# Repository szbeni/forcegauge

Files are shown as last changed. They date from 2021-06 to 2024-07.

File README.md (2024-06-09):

# Force Gauge

- ESP32 based Force Gauge - Aiming to help rock climbing specific training (finger excercises)
- Real time plotting via wifi Webapp/Android app

# Pictures
## Forcegauge with fingerboard
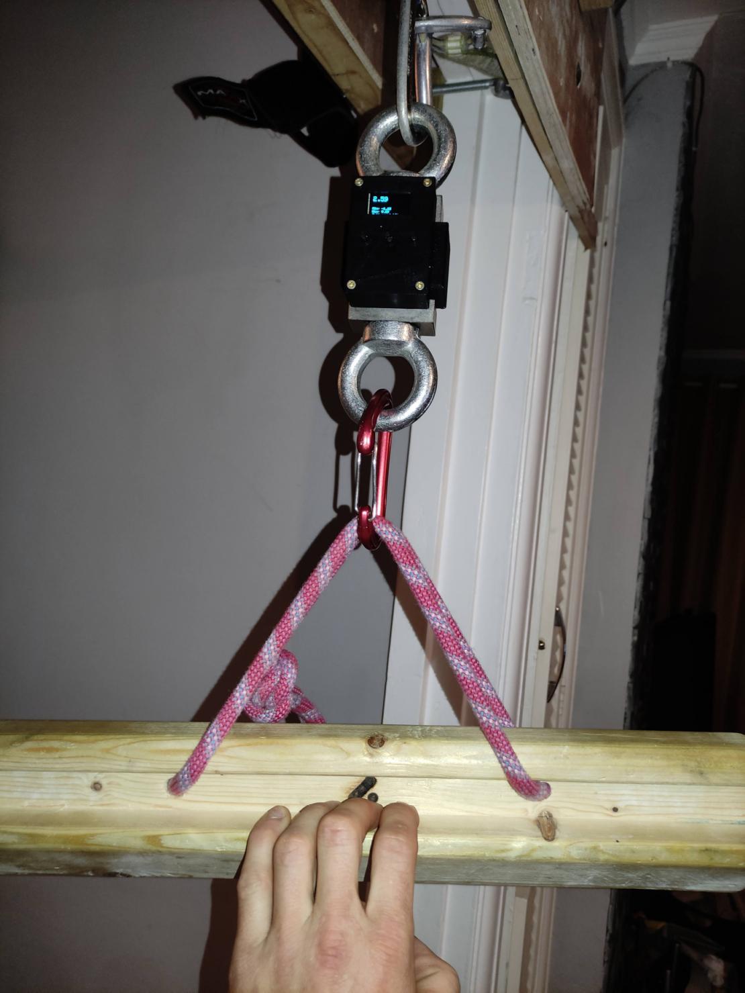
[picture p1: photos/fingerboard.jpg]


## First prototypes
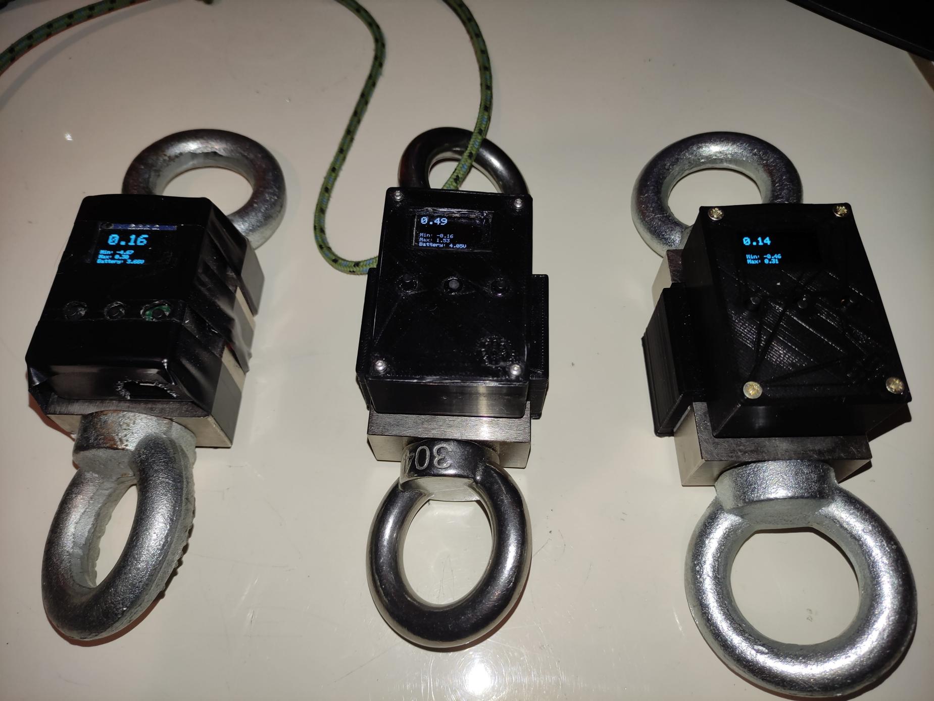
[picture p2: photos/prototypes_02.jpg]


# Hardware
## Main parts
 - ESP32-C3 MCU
 - 3 buttons
 - OLED screen 0.96" SSD1306
 - Battery with charger
 - USB UART connection
 - HX711 ADC - Load cell
## Schematic ##

- [Schematic](https://github.com/szbeni/forcegauge/blob/main/hw/forcegauge/forcegauge.pdf)
## PCB 

Pictures of the PCB:

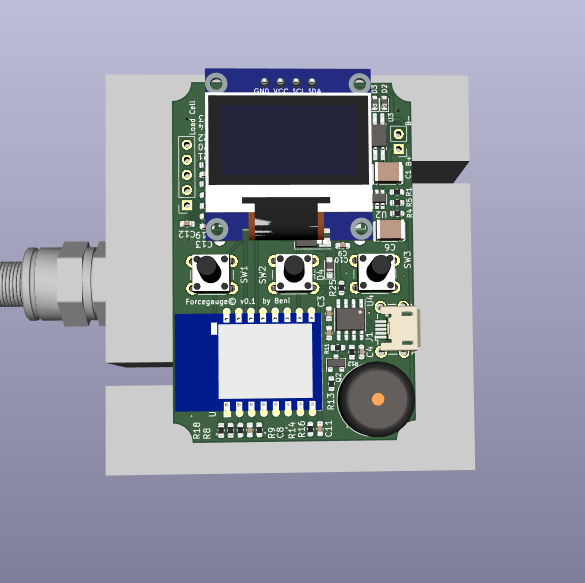
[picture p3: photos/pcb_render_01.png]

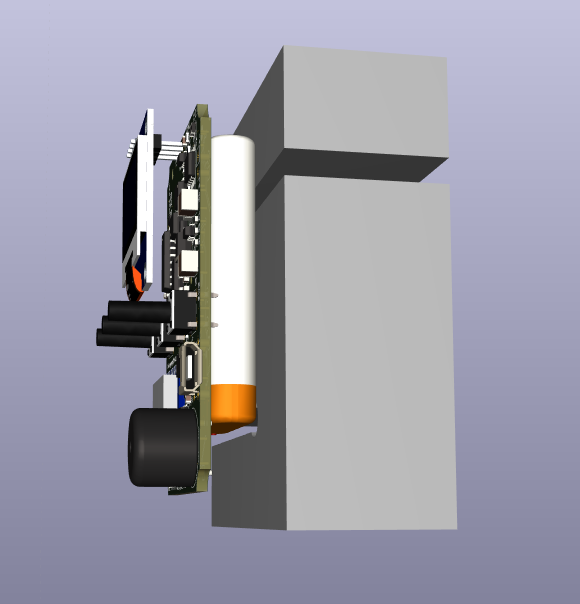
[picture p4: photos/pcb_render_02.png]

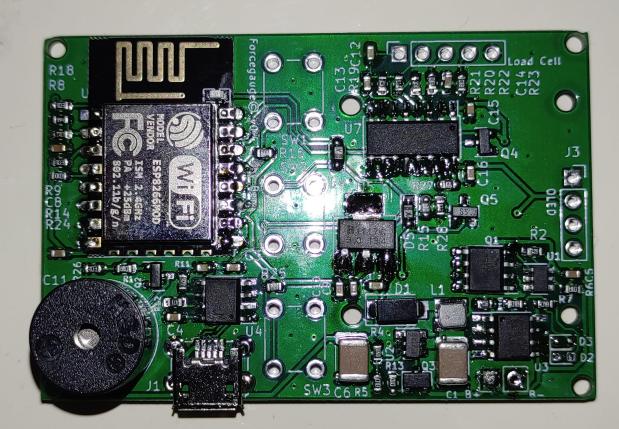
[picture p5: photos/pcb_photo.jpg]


## Interactive BOM

- [Interactive BOM](https://htmlpreview.github.io/?https://github.com/szbeni/forcegauge/blob/main/hw/forcegauge/bom/ibom.html)

# Software

## Firmware
- Arudino IDE - Some lagging issues due to limitations of arduino environment
- Started wokring on firmware with ESP-IDF which supports multitasking
- Added Bluetooth support to come up as a Tindeq Progressor bluetooth device (https://tindeq.com/product/progressor) (CChange Bluetooth and restart device, WIFI wont work when BT is on)
- Added Bluetooth support to come up as a Climbro bluetooth device (https://climbro.com/) (Change Bluetooth settings and restart device, WIFI wont work when BT is on)

## Flutter based app (Tested on Android)
- Available on Google play: https://play.google.com/store/apps/details?id=com.github.szbeni.forcegauge
- Real time plotting
- Built in tabata timer (Based on https://github.com/insin/tabata_timer)
- Record history of traning 

<p float="left">
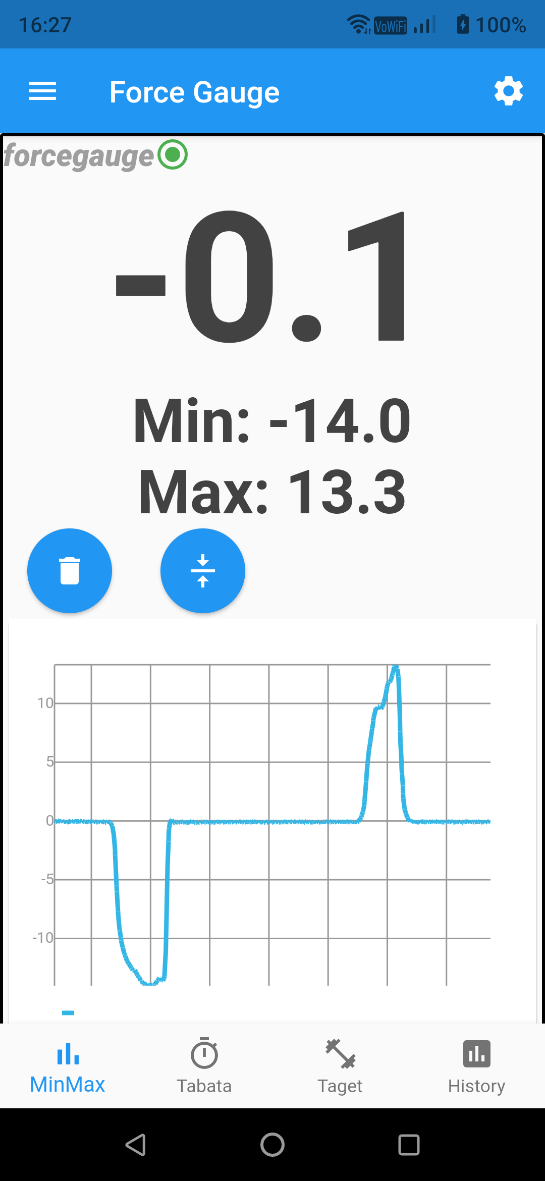
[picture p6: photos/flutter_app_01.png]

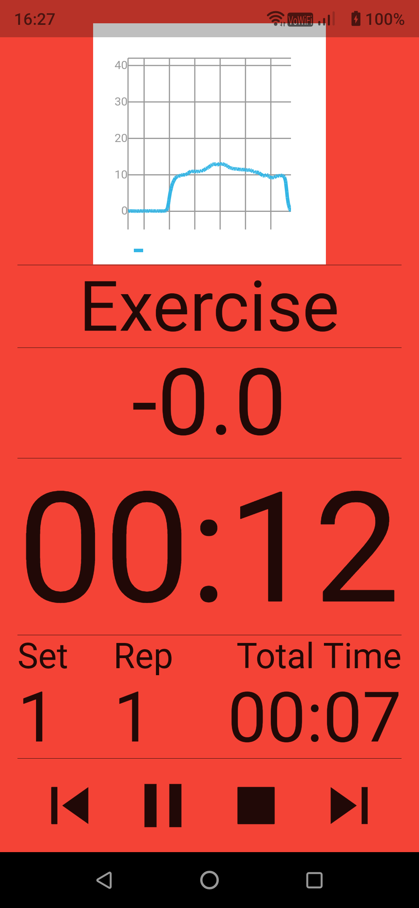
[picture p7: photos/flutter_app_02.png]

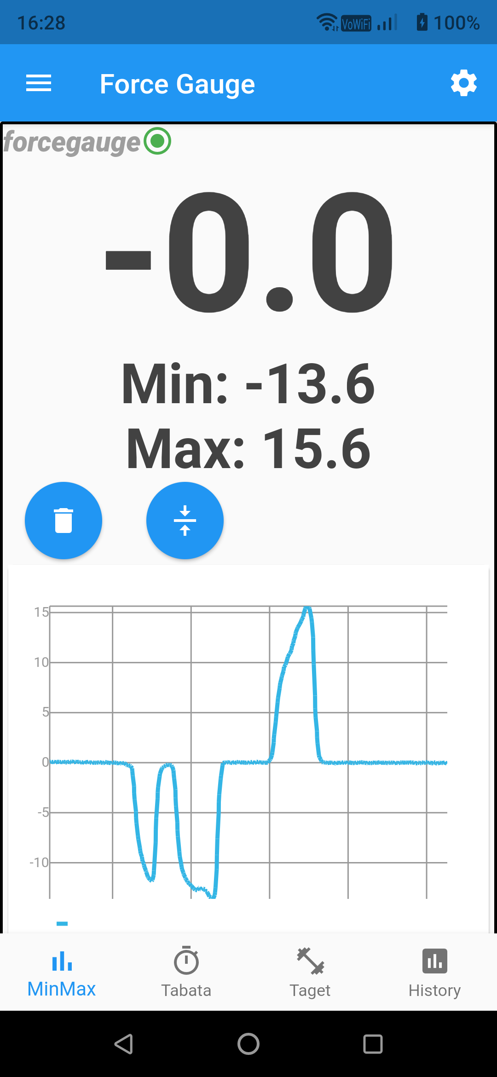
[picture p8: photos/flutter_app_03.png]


</p>

## Webapp
- Simple webapp served from a HTTP server

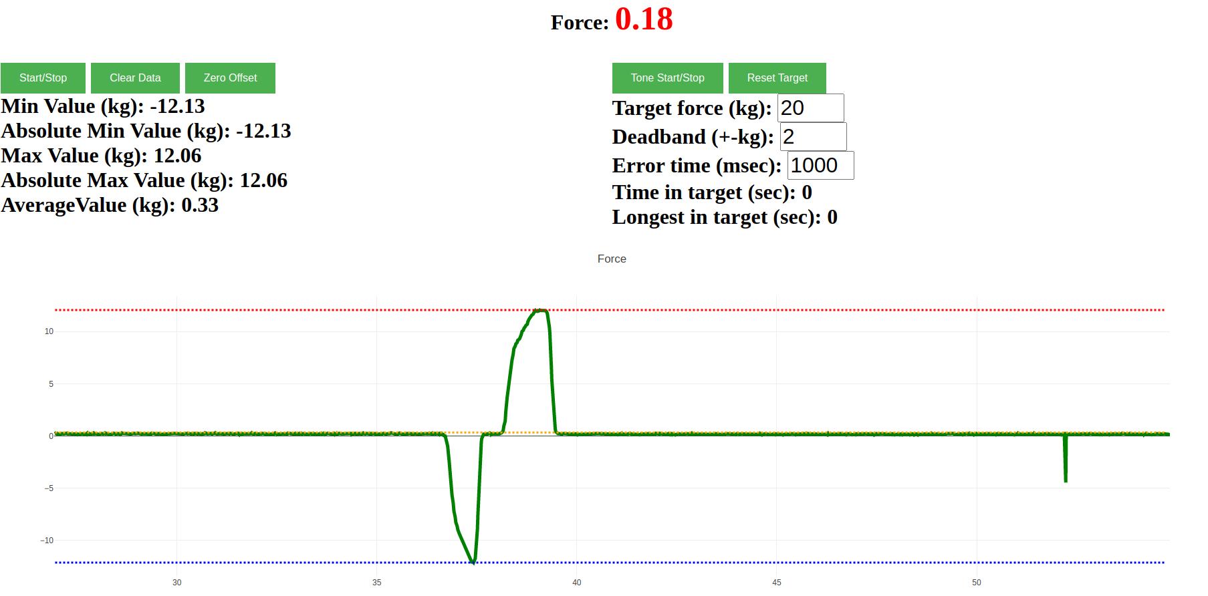
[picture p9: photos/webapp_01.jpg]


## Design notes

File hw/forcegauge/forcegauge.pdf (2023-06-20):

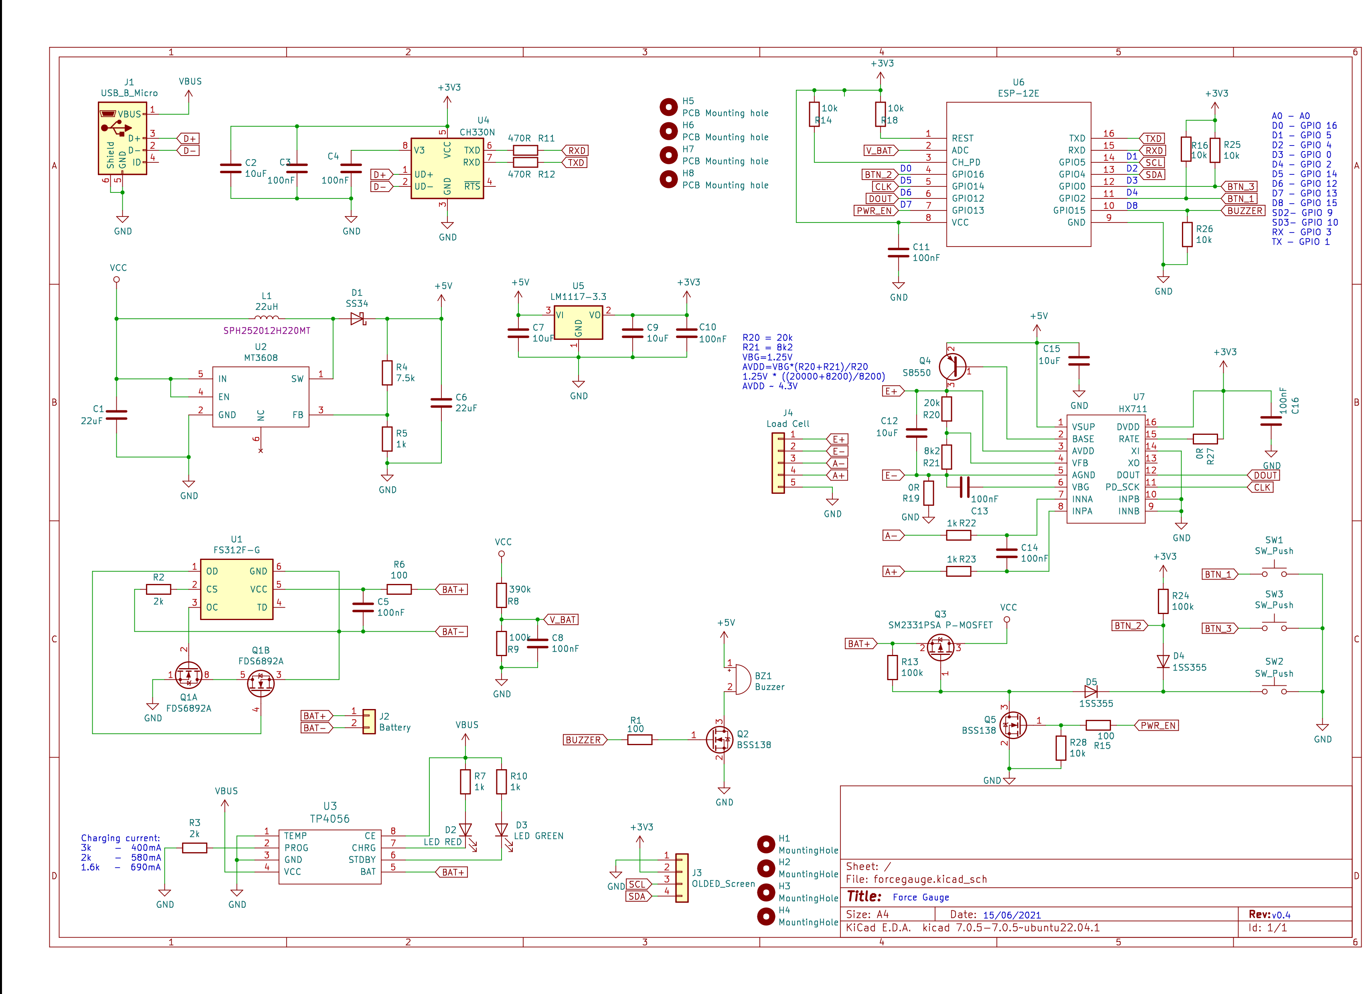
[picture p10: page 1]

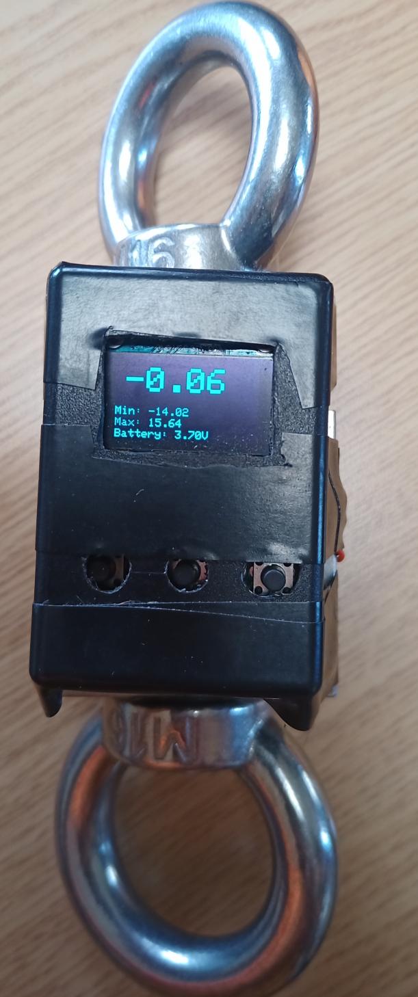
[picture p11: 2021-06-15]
photos/prototype_01.jpg

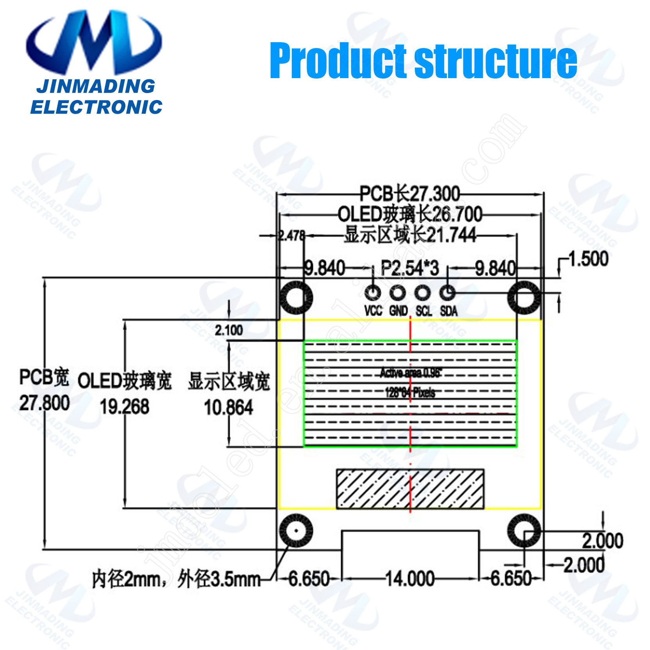
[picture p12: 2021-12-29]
hw/forcegauge/resources/oled_screen_dimensions.jpg

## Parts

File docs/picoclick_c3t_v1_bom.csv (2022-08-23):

Part | Value | Device | Package | Description
BAT+ | TP/SP-1.5X1.0 | TP/SP-1.5X1.0 | SOLDERPAD_1.5X1.0 | Solderpads/Testpads
BAT- | TP/SP-1.5X1.0 | TP/SP-1.5X1.0 | SOLDERPAD_1.5X1.0 | Solderpads/Testpads
C1 | 1µ | C-EU-0402-WOKEEPOUT_S | C0402_S
C2 | 1µ | C-EU-0402-WOKEEPOUT_S | C0402_S
C3 | 1µ | C-EU-0402-WOKEEPOUT_S | C0402_S
C4 | 1µ | C-EU-0402-WOKEEPOUT_S | C0402_S
C7 | 10µ | C-EU-0402-WOKEEPOUT_S | C0402_S
C8 | 0,1µ | C-EU-0402-WOKEEPOUT_S | C0402_S
C9 | 0,1µ | C-EU-0402-WOKEEPOUT_S | C0402_S
C13 | 1µ | C-EU-0402-WOKEEPOUT_S | C0402_S
C20 | 10p | C-EU-0402-WOKEEPOUT_S | C0402_S
C21 | 10p | C-EU-0402-WOKEEPOUT_S | C0402_S
D1 | 4148 | DIODE-SOD523 | SOD523 | DIODE
D2 | 4148 | DIODE-SOD523 | SOD523 | DIODE
ESP1 | ESP32_C3_QFN32 | ESP32_C3_QFN32 | QFN32
F2 | 0 | R-EU-0402-WOKEEPOUT | R0402
L1 | WS2812_2020 | WS2812_2020 | WS2812_2020
R/1 | 1M | R-EU-0402-WOKEEPOUT | R0402
R/2 | 250k | R-EU-0402-WOKEEPOUT | R0402
R1 | 1k | R-EU-0402-WOKEEPOUT | R0402
R2 | 1k | R-EU-0402-WOKEEPOUT | R0402
R3 | 1M | R-EU-0402-WOKEEPOUT | R0402
R4 | 10k | R-EU-0402-WOKEEPOUT | R0402
R5 | 47.5k | R-EU-0402-WOKEEPOUT | R0402
R7 | 10k | R-EU-0402-WOKEEPOUT | R0402
R10 | 10k | R-EU-0402-WOKEEPOUT | R0402
R11 | 10k | R-EU-0402-WOKEEPOUT | R0402
R12 | 5.1k | R-EU-0402-WOKEEPOUT | R0402
R13 | 5.1k | R-EU-0402-WOKEEPOUT | R0402
RF | ANT3216LL00R2400A | ANT3216LL00R2400A | ANT3216LL00R2400A
U$1 | BUTTON_ST-1187-3 | BUTTON_ST-1187-3 | BUTTON_ST-1187-3
U1 | BRCL4054BME | MCP73831_SOT23_5 | SOT23-5
U2 | MIC5504 | MIC5504 | TDFN4
USB-C | USB_C_C393939 | USB_C_C393939 | USBC_C393939
X1 | XTAL_2016 | XTAL_2016 | XTYL_2016

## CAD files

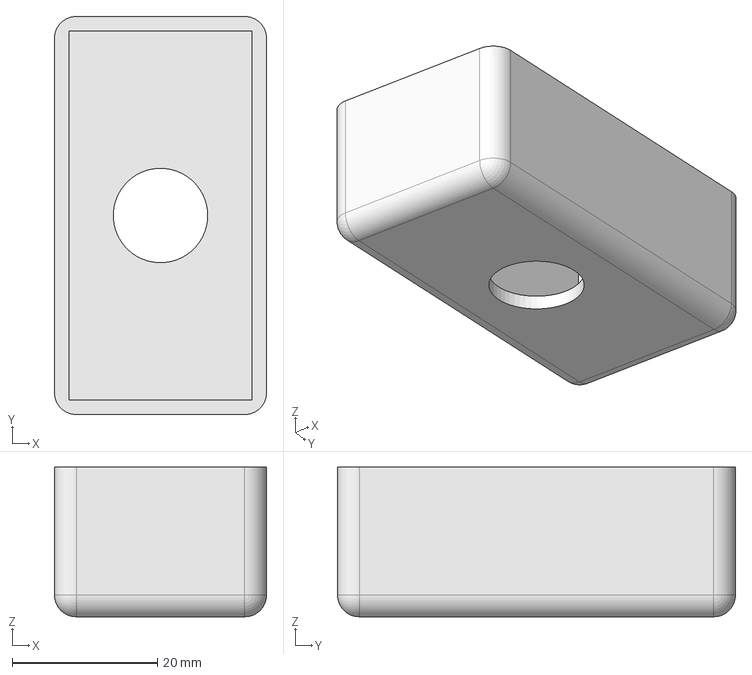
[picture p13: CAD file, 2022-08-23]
hw/box/loadcell_cap_big.FCStd
29.2 x 54.8 x 20.6 mm

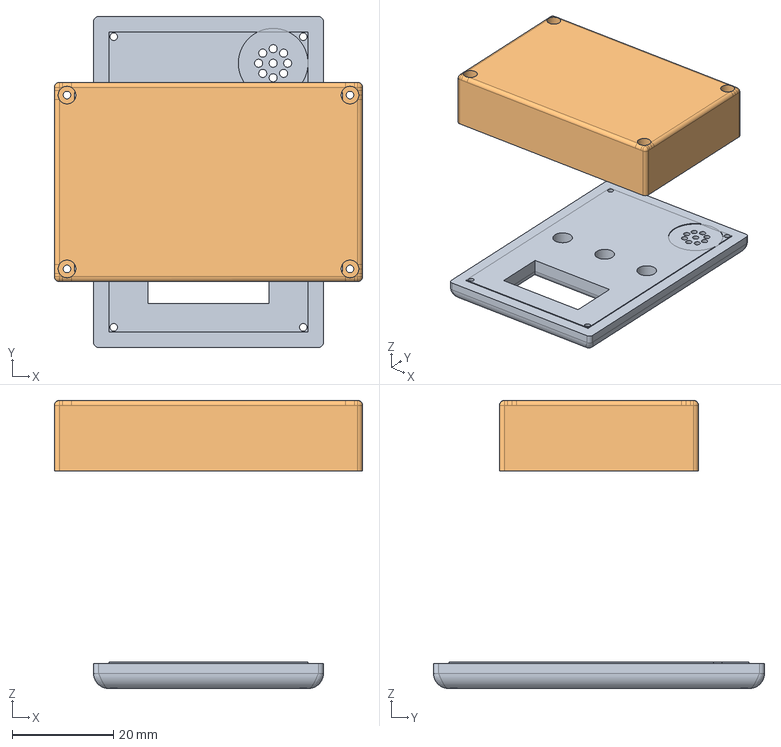
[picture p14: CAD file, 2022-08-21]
hw/box/forcegauge_v2.FCStd
61.0 x 65.5 x 57.0 mm
PCBBoxLid
BatteryHolder

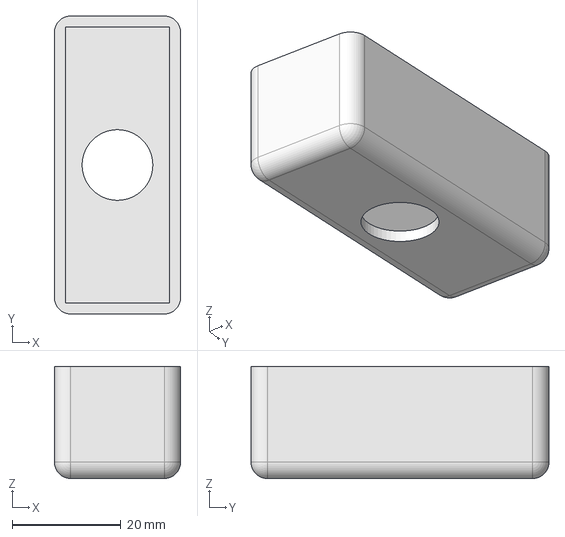
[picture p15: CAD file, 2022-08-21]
hw/box/loadcell_cap_small.FCStd
23.2 x 54.8 x 20.6 mm

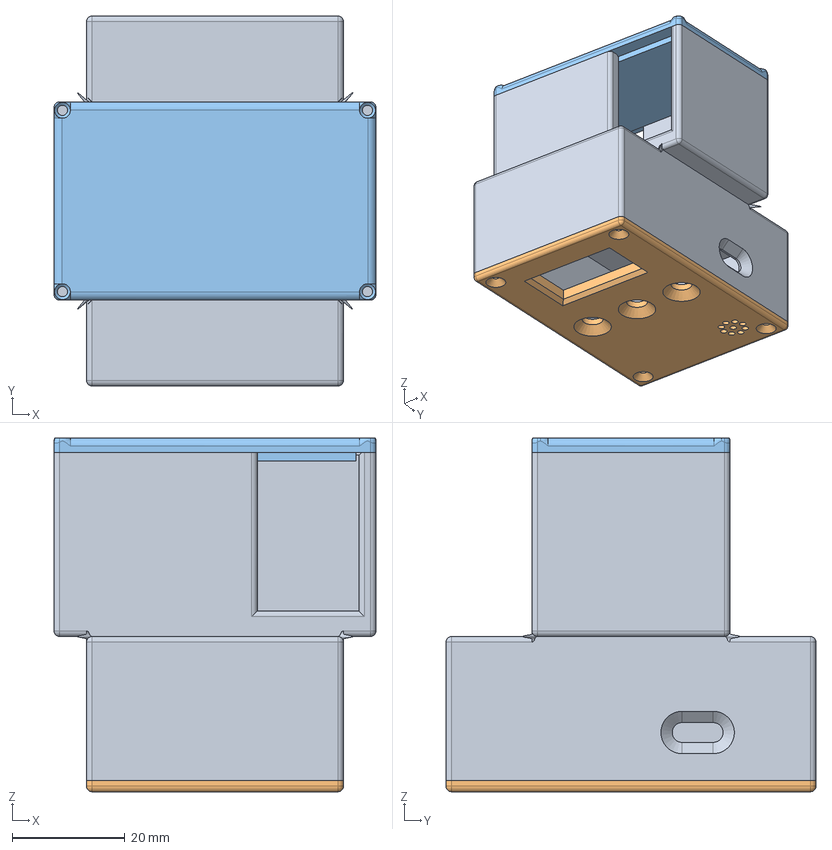
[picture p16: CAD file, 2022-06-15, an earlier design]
hw/box/forcegauge_v1.FCStd
57.0 x 65.5 x 62.6 mm
MainPart
PCBBoxLid
LoadcellLid

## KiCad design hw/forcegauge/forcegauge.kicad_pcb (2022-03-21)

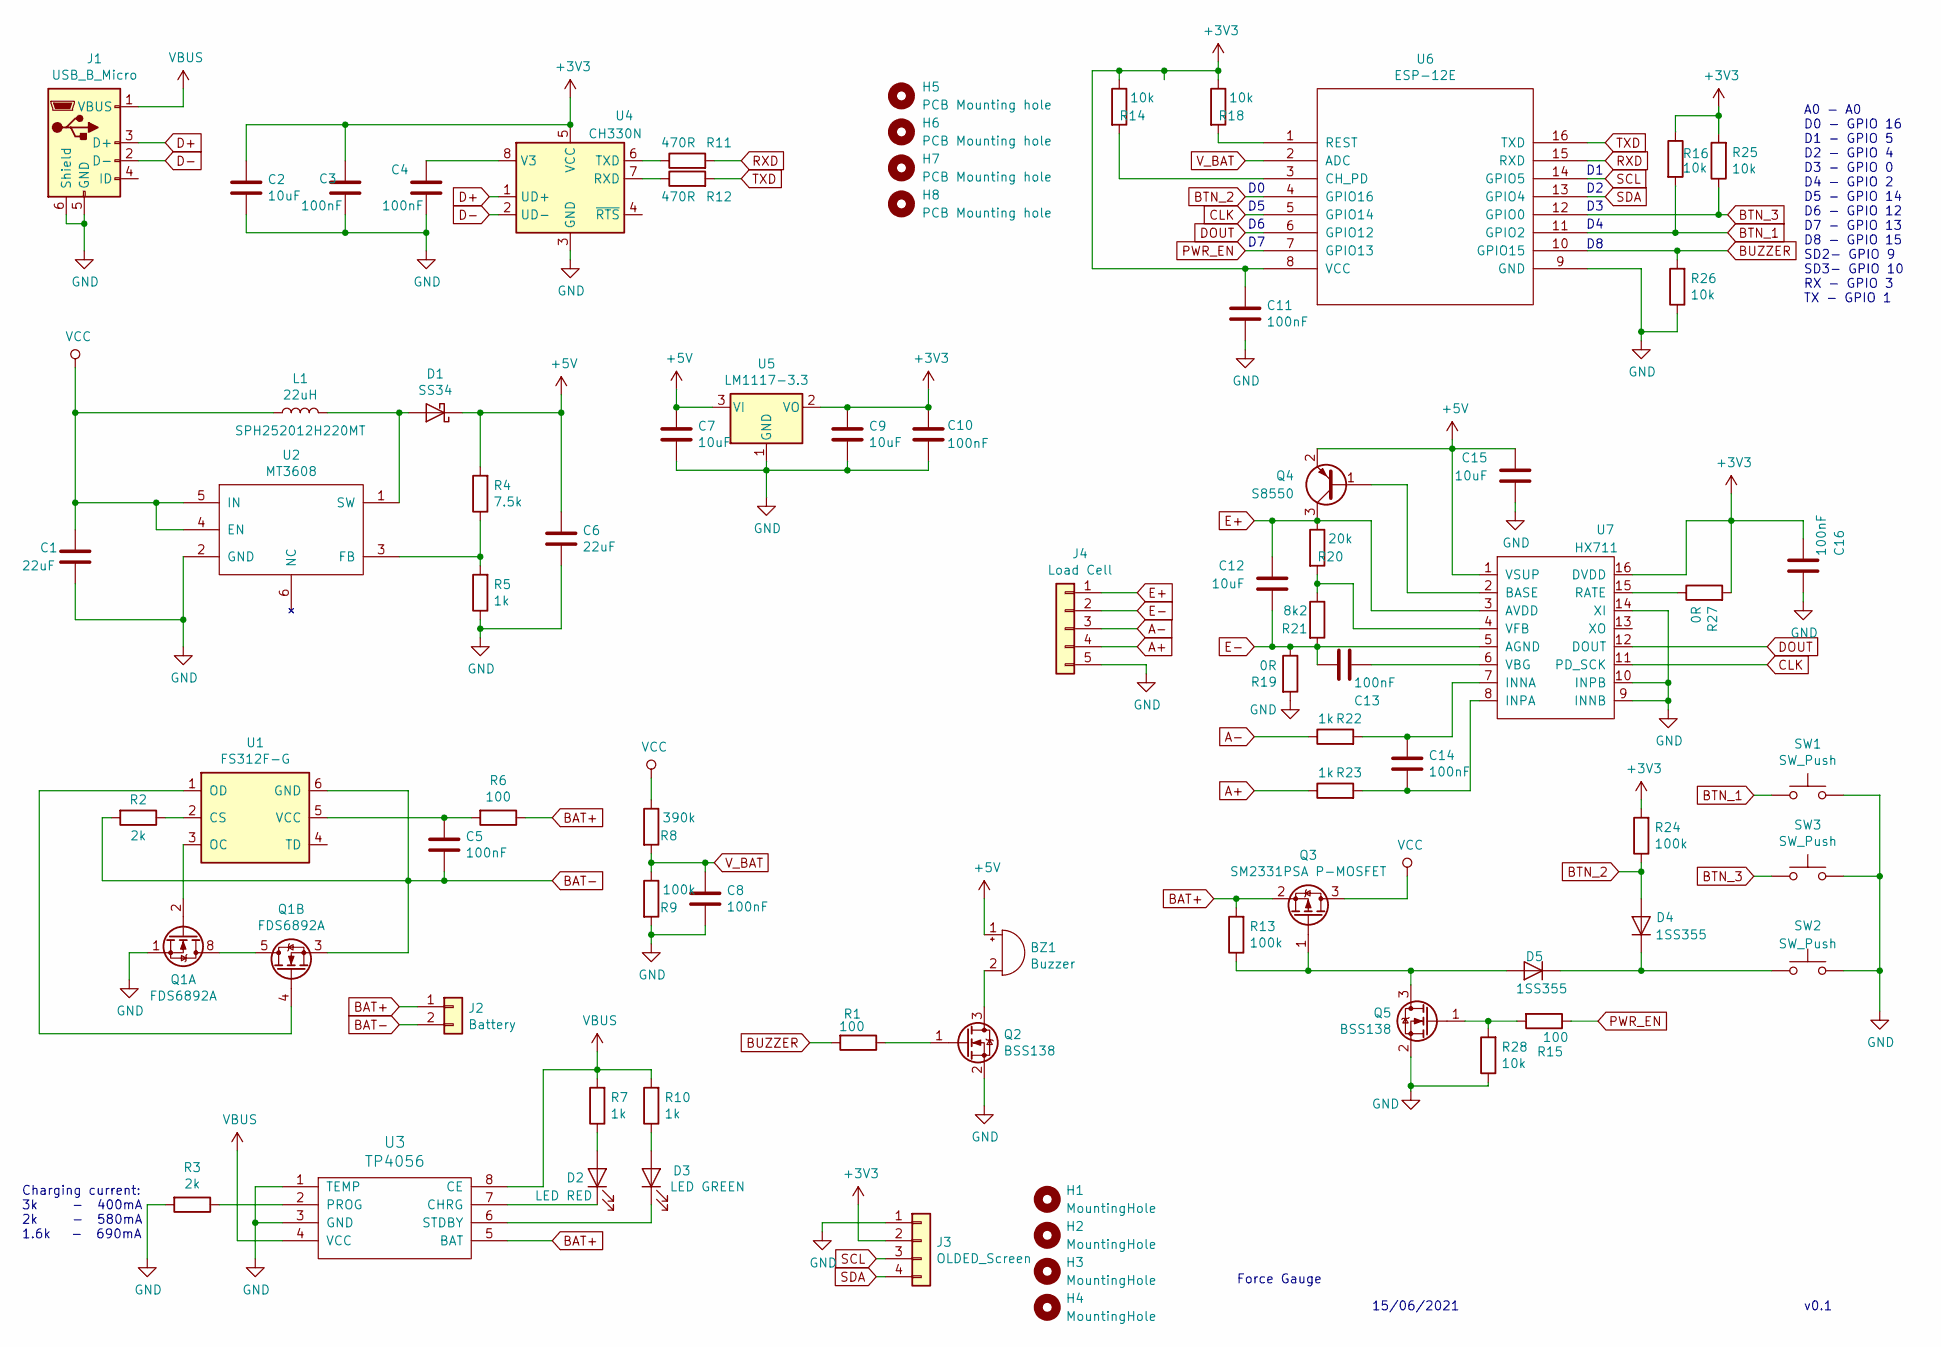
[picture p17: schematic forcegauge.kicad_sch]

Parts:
BZ1: Buzzer; Buzzer_12x9.5RM7.6
C1, C6: 22uF; C_1812_4532Metric
C2, C7, C9, C12, C15: 10uF; C_0603_1608Metric
C3, C4, C5, C8, C10, C11, C13, C14, C16: 100nF; C_0603_1608Metric
D1: SS34; D_SMA
D2: LED RED; D_0603_1608Metric
D3: LED GREEN; D_0603_1608Metric
D4, D5: 1SS355; D_SOD-323_HandSoldering
H1, H2, H3, H4: MountingHole; MountingHole_2mm_OLED
H5, H6, H7, H8: PCB Mounting hole; MountingHole_2mm_OLED
J1: USB_B_Micro; USB_Micro-B_Wuerth_629105150521_CircularHoles
J2: Battery; PinHeader_1x02_P2.54mm_Vertical
J3: OLDED_Screen; PinSocket_1x04_P2.54mm_Vertical
J4: Load Cell; PinSocket_1x05_P2.54mm_Vertical
L1: 22uH; L_Wuerth_MAPI-3012
Q1: FDS6892A; SOIC-8_3.9x4.9mm_P1.27mm
Q2, Q5: BSS138; SOT-23
Q3: SM2331PSA P-MOSFET; SOT-23
Q4: S8550; SOT-23
R1, R6, R15: 100; R_0603_1608Metric
R2, R3: 2k; R_0603_1608Metric
R4: 7.5k; R_0603_1608Metric
R5, R7, R10, R22, R23: 1k; R_0603_1608Metric
R8: 390k; R_0603_1608Metric
R9, R13, R24: 100k; R_0603_1608Metric
R11, R12: 470R; R_0603_1608Metric
R14, R16, R18, R25, R26, R28: 10k; R_0603_1608Metric
R19, R27: 0R; R_0603_1608Metric
R20: 20k; R_0603_1608Metric
R21: 8k2; R_0603_1608Metric
SW1, SW2, SW3: SW_Push; SW_PUSH_6mm
U1: FS312F-G; SOT-23-6
U2: MT3608; SOT-23-6
U3: TP4056; SOP8-PP
U4: CH330N; SOIC-8_3.9x4.9mm_P1.27mm
U5: LM1117-3.3; SOT-223
U6: ESP-12E; ESP-12
U7: HX711; SOP-16_4.55x10.3mm_P1.27mm

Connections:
+5V: BZ1.1 (-), C6.1, C7.1, C15.2, D1.1 (K), Q4.2 (E), R4.2, U5.3 (VI), U7.1 (VSUP)
A+: J4.4, R23.1
A-: J4.3, R22.1
BAT+: J2.1, Q3.2 (S), R6.1, R13.2, U3.5 (BAT)
BAT-: C5.2, J2.2, Q1.3 (S2), R2.2, U1.6 (GND)
BTN_1: R16.2, SW1.1, U6.11 (GPIO2)
BTN_2: D4.2 (A), R24.1, U6.4 (GPIO16)
BTN_3: R25.1, SW3.1, U6.12 (GPIO0)
BUZZER: R1.2, R26.2, U6.10 (GPIO15)
CLK: U6.5 (GPIO14), U7.11 (PD_SCK)
D+: J1.3 (D+), U4.1 (UD+)
D-: J1.2 (D-), U4.2 (UD-)
DOUT: U6.6 (GPIO12), U7.12 (DOUT)
E+: C12.2, J4.1, Q4.3 (C), R20.1, U7.3 (AVDD)
E-: C12.1, C13.2, J4.2, R19.1, R21.2, U7.5 (AGND)
GND: C1.2, C2.2, C3.2, C4.2, C6.2, C7.2, C8.2, C9.2, C10.2, C11.2, C15.1, C16.2, J1.5 (GND), J1.6 (Shield), J3.1, J4.5, Q1.1 (S1), Q2.2 (S), Q5.2 (S), R3.2, R5.1, R9.2, R19.2, R26.1, R28.1, SW1.2, SW2.2, SW3.2, U2.2 (GND), U3.1 (TEMP), U3.3 (GND), U4.3 (GND), U5.1 (GND), U6.9 (GND), U7.9 (INNB), U7.10 (INPB), U7.14 (XI)
unnamed: BZ1.2 (+), Q2.3 (D)
unnamed: C4.1, U4.8 (V3)
unnamed: C5.1, R6.2, U1.5 (VCC)
unnamed: C13.1, U7.6 (VBG)
unnamed: C14.1, R22.2, U7.7 (INNA)
unnamed: C14.2, R23.2, U7.8 (INPA)
unnamed: D1.2 (A), L1.2, U2.1 (SW)
unnamed: D2.1 (K), U3.7 (CHRG)
unnamed: D2.2 (A), R7.1
unnamed: D3.1 (K), U3.6 (STDBY)
unnamed: D3.2 (A), R10.1
unnamed: D4.1 (K), D5.1 (K), SW2.1
unnamed: D5.2 (A), Q3.1 (G), Q5.3 (D), R13.1
unnamed: Q1.2 (G1), U1.3 (OC)
unnamed: Q1.4 (G2), U1.1 (OD)
unnamed: Q1.5 (D2), Q1.6 (D2), Q1.7 (D1), Q1.8 (D1)
unnamed: Q2.1 (G), R1.1
unnamed: Q4.1 (B), U7.2 (BASE)
unnamed: Q5.1 (G), R15.2, R28.2
unnamed: R2.1, U1.2 (CS)
unnamed: R3.1, U3.2 (PROG)
unnamed: R4.1, R5.2, U2.3 (FB)
unnamed: R11.1, U4.6 (TXD)
unnamed: R12.1, U4.7 (RXD)
unnamed: R14.2, U6.3 (CH_PD)
unnamed: R18.2, U6.1 (REST)
unnamed: R20.2, R21.1, U7.4 (VFB)
unnamed: R27.1, U7.15 (RATE)
PWR_EN: R15.1, U6.7 (GPIO13)
RXD: R11.2, U6.15 (RXD)
SCL: J3.3, U6.14 (GPIO5)
SDA: J3.4, U6.13 (GPIO4)
TXD: R12.2, U6.16 (TXD)
VBUS: J1.1 (VBUS), R7.2, R10.2, U3.4 (VCC), U3.8 (CE)
VCC: C1.1, L1.1, Q3.3 (D), R8.1, U2.4 (EN), U2.5 (IN)
V_BAT: C8.1, R8.2, R9.1, U6.2 (ADC)

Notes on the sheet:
v0.1
A0 - A0 D0 - GPIO 16 D1 - GPIO 5 D2 - GPIO 4 D3 - GPIO 0 D4 - GPIO 2 D5 - GPIO 14 D6 - GPIO 12 D7 - GPIO 13 D8 - GPIO 15 SD2- GPIO 9 SD3- GPIO 10 RX - GPIO 3 TX - GPIO 1
Force Gauge
15/06/2021
Charging current: 3k - 400mA 2k - 580mA 1.6k - 690mA

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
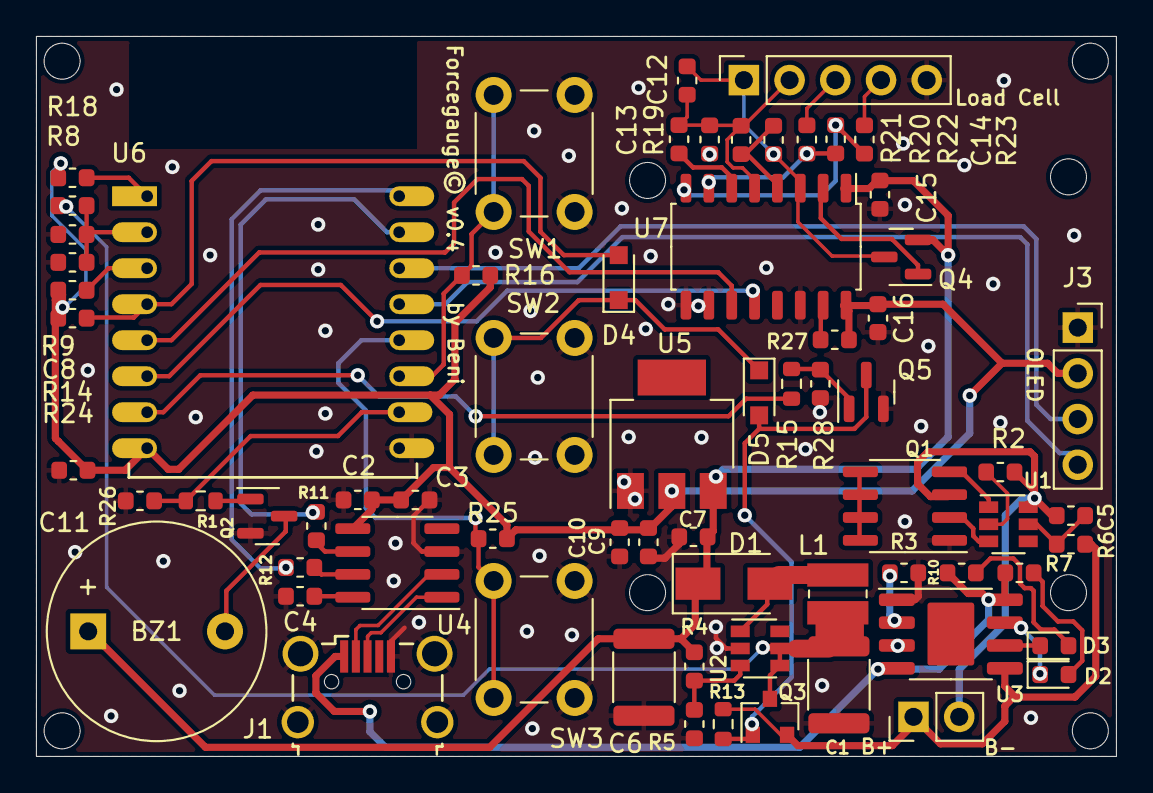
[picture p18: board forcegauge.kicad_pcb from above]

Board: 2 copper layers, 60.0 x 40.0 mm, 77 parts (0 on the bottom side), 53 nets.

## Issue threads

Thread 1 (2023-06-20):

Excitation voltage

tomhaber, 2023-06-20:
What kind of load cell are you using? Am I correct that since R20=20k and R21=8k2, the excitation voltage as well as AVDD will be 1.75V? What is the rated output of your load cell?

Thanks in advance

szbeni, 2023-06-20:
Hi!
Yeah you are right. It looks like it's wrong on the schematic. I think I put around 4V excitation on the actual hardware and forgot to change it on the schematic.
I will check what I actually used, but something like 4k7 and 10k
R20 = 4k7
R21 = 10k
VBG=1.25V
AVDD=VBG*(R20+R21)/R20 =1.25V * ((4k7+10k)/4k7) =>  3.91V

I will correct it, thanks.

szbeni, 2023-06-20:
Updated the schematic with the calculation.
The loadcells I am using:
https://www.aliexpress.com/item/1005002046379393.html?spm=a2g0o.order_list.order_list_main.87.21ef1802pDKxhM

Rated output: 2mV/V
So it would give 8.6mV at full scale with 4.3V excitation.

Closed 2023-06-20.

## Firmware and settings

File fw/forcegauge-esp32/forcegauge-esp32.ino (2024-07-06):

#include "forcegauge.h"
#define VERSION "1.0.11"

configStruct config;
const char configFilename[] = "/config.json";
const char tabatasFilename[] = "/tabatas.json";
const char version[] = VERSION;

HX711 scale;
RingBuf<dataStruct, 32> websocketBuffer;
RingBuf<dataStruct, 32> bluetoothBuffer;

ScreenHandler screenHandler; // Screen hanlder
float maxForce = 0;
float minForce = 0;

TaskHandle_t wifiTaskHandle;
TaskHandle_t httpServerTaskHandle;
TaskHandle_t websocketServerTaskHandle;
TaskHandle_t bluetoothTaskHandle;
TaskHandle_t screenTaskHandle;
TaskHandle_t webUpdateTaskHandle;

void setup()
{
  Serial.begin(115200); // Start Serial
  startBuzzer();
  startButtons();
  startConfig();
  startScreen();
  startHX711();
  startTabata();

  // func| name | Stack in word | param | priority | handle
  // Increase current thread priority
  vTaskPrioritySet(NULL, (configMAX_PRIORITIES - 1));

  xTaskCreate(screenTask, "screenTask", 8192, NULL, tskIDLE_PRIORITY + 1, &screenTaskHandle);

  // Bluetooth, doesnt work very well with WiFi simultaneously
  // as we are sending quite frequent updates from our sensor
  // and switching time of the hardware radio between BLE and WiFi is not very fast.
  // (Same hw is used for both WiFi and Bluetooth)
  if (config.bluetoothEnable != 0)
  {
    if (config.bluetoothEnable == BLUETOOTH_TYPE_TINDEQ)
    {
      xTaskCreate(bluetoothTaskTindeq, "bluetoothTaskTindeq", 20000, NULL, tskIDLE_PRIORITY + 1, &bluetoothTaskHandle);
    }
    else if (config.bluetoothEnable == BLUETOOTH_TYPE_CLIMBRO)
    {
      xTaskCreate(bluetoothTaskClimbro, "bluetoothTaskClimbro", 20000, NULL, tskIDLE_PRIORITY + 1, &bluetoothTaskHandle);
    }
    else if (config.bluetoothEnable == BLUETOOTH_TYPE_SMARTBOARD)
    {
      xTaskCreate(bluetoothTaskSmartBoard, "bluetoothTaskSmartboard", 20000, NULL, tskIDLE_PRIORITY + 1, &bluetoothTaskHandle);
    }
  }
  else
  {

    startWifi();
    // xTaskCreate(webupdateTask, "webupdateTask", 20000, NULL, tskIDLE_PRIORITY + 1, &webUpdateTaskHandle);
    xTaskCreate(wifiTask, "wifiTask", 8192, NULL, tskIDLE_PRIORITY + 1, &wifiTaskHandle);
    xTaskCreate(httpServerTask, "httpServerTask", 80000, NULL, tskIDLE_PRIORITY + 1, &httpServerTaskHandle);
    // High prio task
    xTaskCreate(websocketServerTask, "websocketServerTask", 8192, NULL, configMAX_PRIORITIES - 1, &websocketServerTaskHandle);
  }
}

void loop()
{
  static int spike_cntr = 0;
  // static int32_t cntr = 0;
  // if (true)
  // TODO: use interrupt
  if (scale.is_ready())
  {
    dataStruct data;
    data.v = scale.read();
    //    data.v = cntr;
    //    cntr += 20;
    //    if (cntr > 100000)
    //      cntr = 0 ;

    //data.t = config.time + millis();
    data.t = millis();
    float value = (data.v - config.offset) * config.scale;

    float diff = fabsf(value - config.lastValue);
    // Filter out sudden spikes in reading, max 10 times in a row
    if (diff > 30 && spike_cntr < 10)
    {
      Serial.print("Spike filter: ");
      Serial.print(config.lastValue);
      Serial.print(" ");
      Serial.println(value);
      spike_cntr++;
    }
    else
    {
      config.lastRawValue = data.v;
      websocketBuffer.lockedPush(data);
      bluetoothBuffer.lockedPush(data);
      spike_cntr = 0;
      config.lastValue = lowpassfilter(value, config.lastValue, config.filterCoeff);
      if (config.lastValue > maxForce)
        maxForce = config.lastValue;
      if (config.lastValue < minForce)
        minForce = config.lastValue;
    }
  }
  delay(2);
}

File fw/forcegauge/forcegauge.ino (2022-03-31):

#include "forcegauge.h"

const char configFilename[] = "/config.json";
const char version[] = "1.0.0"; 

configStruct config;
HX711 scale;
RingBuf<dataStruct, 64> dataBuffer;

IPAddress apIP(192, 168, 4, 1);
ESP8266WiFiMulti wifiMulti;       // Create an instance of the ESP8266WiFiMulti class, called 'wifiMulti'
ESP8266WebServer server(80);      //Server on port 80
WebSocketsServer webSocket(81);   // create a websocket server on port 81
File fsUploadFile;                  // a File variable to temporarily store the received file
DNSServer dnsServer;              //DNS server for captive portal
ScreenHandler screenHandler;      //Screen hanlder
float maxForce=0;
float minForce=0;


void setup() {
  Serial.begin(115200); // Start Serial
  startBuzzer();
  startButtons();
  startSPIFFS();
  startConfig();
  startScreen();
  startHX711();
  startWiFi();
}

bool wifiInitialized = false;
void WiFiLoop()
{
  if(wifiInitialized == false)
  {
    
      if (checkWifiConnected())
      {
        startOTA();
        startDNSServer();
        //startMDNS();
        startWebSocket();
        startServer();
        wifiInitialized = true;
      }
  }
  else
  {
    ArduinoOTA.handle();
    webSocket.loop();                           // constantly check for websocket events
    server.handleClient();
    //MDNS.update();
    dnsServer.processNextRequest();
  }
}

static float lowpassfilter(float new_input, float current, float coeff)
{
  return coeff * current + (1 - coeff) * new_input;
}


static unsigned long lastRefresh = millis();

void loop() {
  WiFiLoop();
  buzzerLoop();
  buttonsLoop();
  
  if(millis() - lastRefresh >= 50)
  {
    lastRefresh = millis();
    screenLoop();
  } 
    
  if (scale.is_ready())
  {
    dataStruct data;
    data.v = scale.read();
    data.t = config.time + millis();
    dataBuffer.lockedPush(data);
    float value = (data.v - config.offset) * config.scale;
    //Add simple filter
    config.lastValue = lowpassfilter(value, config.lastValue, config.filterCoeff);
    if (config.lastValue > maxForce)
      maxForce = config.lastValue;
    if (config.lastValue < minForce)
      minForce = config.lastValue;


    if(wifiInitialized)
      webSocketBroadcastData(&data);
  }
  yield();
}

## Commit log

2021-01-19 added sample device
2021-03-28 added device discovery screen
2021-04-18 scan device fix, target force fix
2021-05-09 buttons, buzzer, battery voltage
    [buttons.ino, forcegauge.h, forcegauge.ino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]
2021-05-15 added button navigation, TODO: clean up the mess:)
2021-05-18 schematic started
    [forcegauge.kicad_pcb, forcegauge.sch]
2021-05-23 schematic updated
    [forcegauge.sch]
2021-06-15 added schematic
    [forcegauge.sch]
2021-06-15 schematic added
2021-06-26 schematic updated + footprints started
2021-06-26 more footprints
    [forcegauge.sch]
2021-10-09 PCB updates
    [forcegauge.kicad_pcb, forcegauge.sch]
2021-12-28 kicad 6, pcb WIP
    [forcegauge.kicad_pcb]
2021-12-29 pcb WIP
    [forcegauge.kicad_pcb, forcegauge.kicad_sch]
2022-02-05 pcb routing finished, todo check
    [forcegauge.kicad_pcb, forcegauge.kicad_sch]
2022-02-05 pcb v0.1 sent
    [forcegauge.kicad_pcb, forcegauge.kicad_sch]
2022-02-05 added bom
    [forcegauge.kicad_pcb]
2022-02-08 3d printed box WIP, pcb 3d model
    [forcegauge.FCStd, forcegauge.kicad_pcb]
2022-02-17 button dir updated, fixed footprints and changed dual fet
    [forcegauge.kicad_pcb, forcegauge.kicad_sch]
2022-02-19 pcb v0.2 fixed errors
    [forcegauge.kicad_pcb, forcegauge.kicad_sch]
2022-02-20 box updated
    [forcegauge.FCStd]
2022-02-23 box updateds
    [forcegauge.FCStd]
2022-02-24 pcb and box updata
    [forcegauge.FCStd, forcegauge.kicad_pcb, forcegauge.kicad_sch]
2022-02-26 v0.3 pcb
    [forcegauge.kicad_pcb, forcegauge.kicad_sch]
2022-03-10 pcb updated v0.3 working
    [forcegauge.kicad_sch]
2022-03-21 pcb v0.4
    [forcegauge.FCStd, forcegauge.kicad_pcb, forcegauge.kicad_sch]
2022-03-31 started esp idf version
    [partitions.csv]
2022-04-11 added pdf schematic
    [forcegauge.kicad_sch]
2022-04-11 added pdf schematic to readme
2022-04-11 version number updated on schematic
    [forcegauge.kicad_sch]
2022-04-11 Fingerboard picture and updated readme
2022-05-02 ditched esp sdk.. change to esp-c3-12f instead which has better library support
    [partitions.csv]
2022-05-07 esp32 code started
2022-05-09 esp32 WIP
2022-05-10 esp32-c WIP
2022-05-11 flutter app updated, esp32 nearly working, ranndom crashes..
    [forcegauge-esp32.ino, forcegauge.h, hx711_custom.cpp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]
2022-05-12 dropped asynclibs as they are full of bugs
    [config.ino, forcegauge-esp32.ino, forcegauge.h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]
2022-05-12 captive portal + other fixes
    [buttons.ino, forcegauge-esp32.ino, forcegauge.h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]
2022-05-13 Create fw-esp32.yml
    CI test
2022-05-16 updated partitions and added mkspiffs and bluetooth enable option, which disables wifi
    [partitions.csv]
2022-05-21 tabata started on device
2022-05-23 workout end buzz tweak
    [screenTabata.ino]
2022-05-24 aded option to send tabatas to device
2022-06-10 adc updated, box updated, added flash script
    [forcegauge.FCStd]
2022-06-16 bugfixes and improvements, dropped bluetooth for now
    [buttons.ino, forcegauge-esp32.ino, forcegauge.h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]
2022-07-02 added udp boradcast message some more HW models
    [forcegauge_v2.FCStd, loadcell_cap_small.FCStd]
2022-07-03 battery indicator + screen updates
2022-08-21 login page improvements
    [forcegauge_v2.FCStd, loadcell_cap_small.FCStd]
2022-08-23 more spike filter
2022-08-23 webupdate ota attempt failed added some docs
    [loadcell_cap_big.FCStd, picoclick_c3t_v1_bom.csv]
2023-06-20 excitation voltage resistor values updates
    [forcegauge.kicad_sch]
2023-06-20 revert back values as they were right but updated the calculation
    [forcegauge.kicad_sch]
2024-06-08 fixed config save bug
    [screen.ino]
2024-06-10 screen fix for smartboard
    [screen.ino]
2024-07-06 added auto power off
